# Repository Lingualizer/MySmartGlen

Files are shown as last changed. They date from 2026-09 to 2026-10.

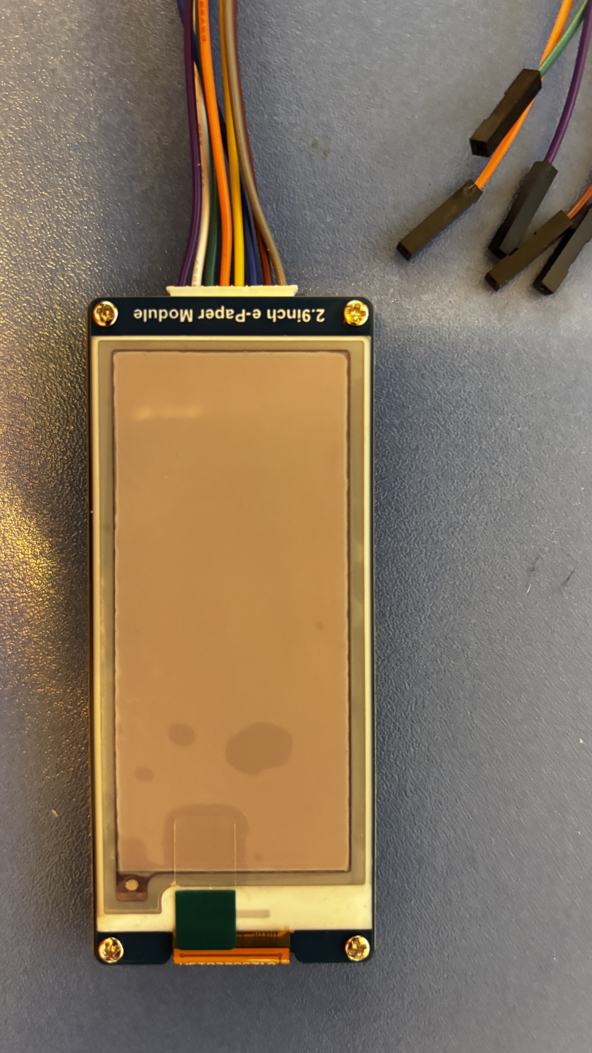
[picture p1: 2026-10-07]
Components/2.9 e-Paper Waveshare/2.9 Waveshare ePaper FRONT.jpeg

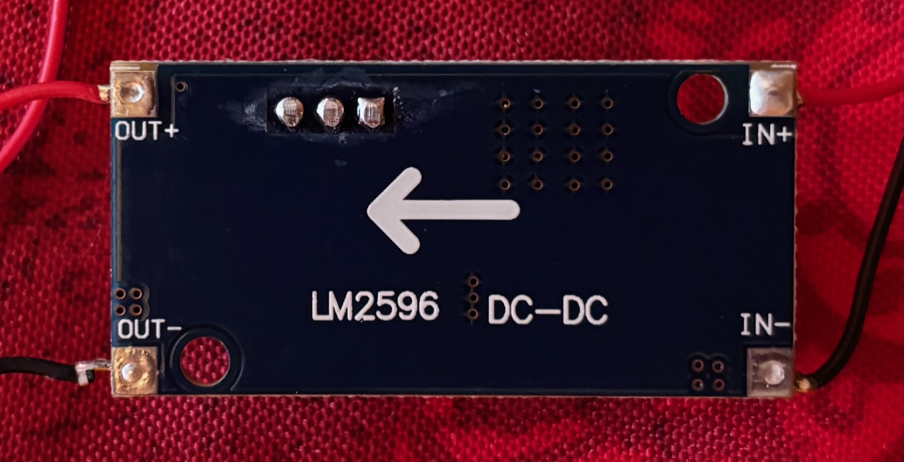
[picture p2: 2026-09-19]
Components/LM2596/LM2596 DC-DC bottom.jpeg

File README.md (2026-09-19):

## Hardware-Übersicht

### Controller & Module
| 🟡 Testaufbau | 🟢 Verbaut | 🔴 Geplant |
| Node ID | Board / Chip | Standby / Load | Bus / IP | Einbauort | Status | Link |
| :--- | :--- | :--- | :--- | :--- | :--- | :--- |
| `Display` | ESP32-S3 (4" Touch) | ~150mA | 192.168.1.220 | Sitzgruppe | 🟡 |  |
| `KS Abluft` | ESP32 NodeMCU | ~80mA | 192.168.1.228 | Hinter Kühlschrank-Gitter | 🟡 | https://www.amazon.de/dp/B0FRF24HL9 |
| `Frischschwasser` | ESP32 NodeMCU | ~50mA | 192.168.1.197 | Sitzbank / Tankbereich | 🟡 | https://www.amazon.de/dp/B0FRF24HL9 |

### Verbaute Sensoren & Aktoren
| Komponente | Typ / Modell | Angeschlossen an | Signal / Protokoll | Pins (ESP32) |
| :--- | :--- | :--- | :--- | :--- |
| Abluft-Sensor | SHT31 | `esp-fridge` | OneWire | GPIO 4 |
| Innen-Temp. | ? | `esp-fridge` | OneWire | GPIO 4 (Bus) |
| Gefrierfach-Temp. | ? | `esp-fridge` | OneWire | GPIO 4 (Bus) |
| Abluft-Lüfter | 12V Noctua PWM | `esp-fridge` | PWM / MOSFET | GPIO 16 (PWM), GPIO 17 (Tacho) |
| Urintank Level | XKC-Y25-V (Kapazitiv) | `esp-tanks` | Digital (High/Low) | GPIO 18 |
| Frischwasser | 10-Stufen-Sonde | `esp-tanks` | Analog / ADC | GPIO 34 |

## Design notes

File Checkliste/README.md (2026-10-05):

# Abfahrts-Checkliste

Eigenstaendiges PlatformIO-Projekt fuer ein ESP32-DevKit und ein
Waveshare 2.9-inch e-Paper V2 (296 x 128, schwarz/weiss, SSD1680). Die
Firmware nimmt diese Panel-Revision an; bei einer aelteren 2.9-inch-Version
muss der GxEPD2-Paneltyp angepasst werden.

## Bedienung

Mit `Hoch` und `Runter` wird der Cursor durch die Liste bewegt. Die
Navigation laeuft am Listenende weiter zum Anfang und umgekehrt. Ein kurzer
Druck auf `Auswahl` setzt oder entfernt das Haekchen des markierten Punkts.
Wird `Auswahl` 1,2 Sekunden gehalten, werden alle Haekchen geloescht und der
Cursor springt zum ersten Eintrag. Sind alle Punkte bestaetigt, erscheint
gross **OK**. Der Zustand wird nicht dauerhaft gespeichert und startet nach
einem Neustart wieder offen.

## Liste anpassen

Pruefpunkte werden in `src/main.cpp` im Array `checklist` gepflegt:

```cpp
{"Gasflasche geschlossen", false},
```

Weitere Eintraege vor der schliessenden Klammer des Arrays ergaenzen. Die
Anzeige scrollt automatisch mit dem Cursor und zeigt jeweils bis zu acht
Punkte.

## Verdrahtung

Verdrahtungsschaltplan

| Signal | ESP32 GPIO |
| --- | ---: |
| e-Paper CLK (ESP32 SCK) | 18 |
| e-Paper MOSI / DIN | 23 |
| e-Paper CS | 5 |
| e-Paper DC | 17 |
| e-Paper RST | 16 |
| e-Paper BUSY | 4 |
| Hoch | 33 |
| Runter | 32 |
| Auswahl / lang halten fuer Reset | 25 |

Alle Taster werden zwischen ihrem GPIO und GND angeschlossen. Die Firmware
aktiviert `INPUT_PULLUP`; ein Tastendruck ist daher LOW. Das Display wird
mit 3.3 V betrieben. Beim e-Paper-Modul die beschrifteten Anschluesse
verwenden und nicht mit 5 V versorgen.

`CLK` am Waveshare-Modul ist derselbe SPI-Takt wie `SCK` am ESP32: GPIO 18
geht an `CLK`, GPIO 23 (MOSI) geht an `DIN`. Diese beiden Leitungen nicht
vertauschen.

## Bauen und Flashen

Im Ordner `Checkliste`:

```sh
pio run
pio run --target upload
pio device monitor
```

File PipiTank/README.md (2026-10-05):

# PipiTank-Sensortest

Serieller Funktionstest fuer die zwei XKC-Y25-NPN-Sensoren gemaess
`Urintank-Schaltplan.pdf`.

## Belegung

| Signal | Anschluss |
| --- | --- |
| Sensor 1 OUT, gelb | ESP32 GPIO 18 |
| Sensor 2 OUT, gelb | ESP32 GPIO 19 |
| Beide Sensoren GND, blau | Gemeinsame Masse mit ESP32 |
| Beide Sensoren VCC, braun | 12-V-Versorgung gemaess Schaltplan |
| Mode, schwarz | Nicht angeschlossen gemaess Schaltplan |

Die gelben NPN-Open-Collector-Ausgaenge werden mit `INPUT_PULLUP` gelesen.
LOW bedeutet Sensor erkannt, HIGH bedeutet nicht erkannt. Die 12-V-Versorgung
nicht mit einem ESP32-GPIO verbinden; nur die OUT-Leitung geht an den GPIO.

## Testen

Im Ordner `PipiTank` ausfuehren:

```sh
pio run
pio run --target upload
pio device monitor
```

Der serielle Monitor laeuft mit 115200 Baud und gibt beide Pegel zweimal pro
Sekunde samt Rohwert aus.

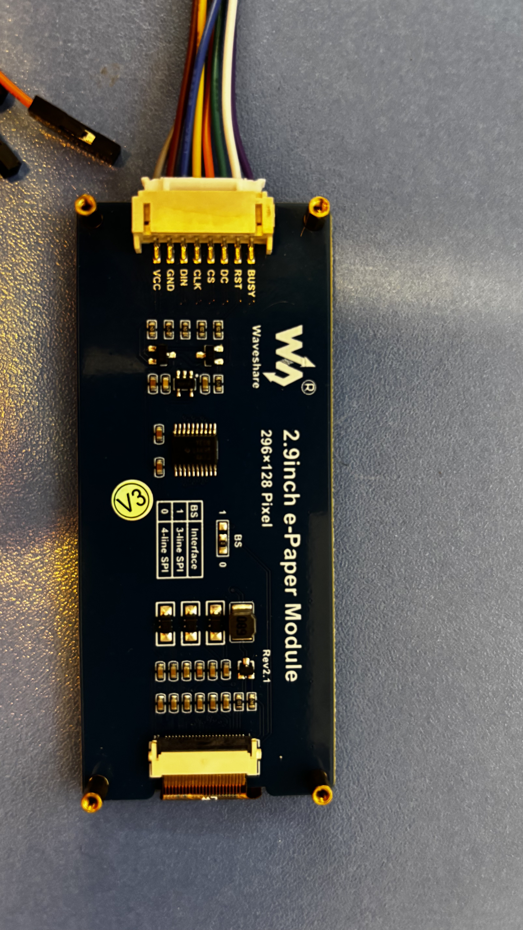
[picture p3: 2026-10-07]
Checkliste/2.9 Waveshare ePaper back.jpeg

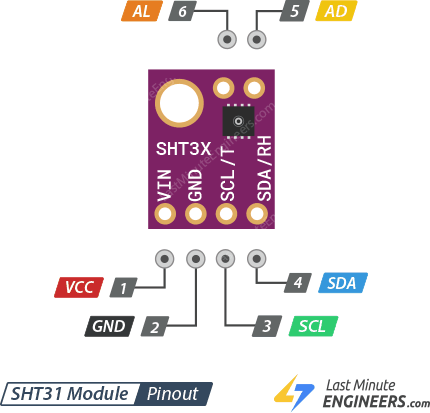
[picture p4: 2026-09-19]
Components/SHT31/SHT31-Module-Pinout.png

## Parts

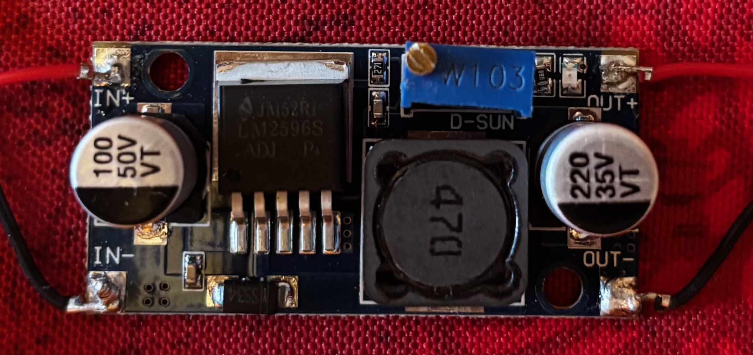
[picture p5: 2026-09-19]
Components/LM2596/LM2596 DC-DC top.jpeg

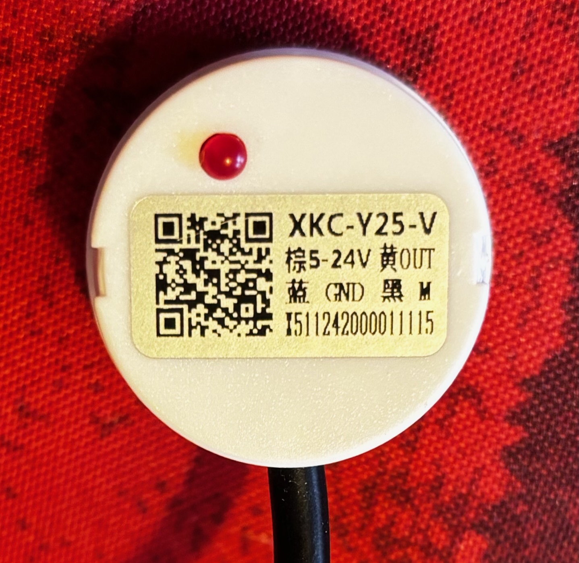
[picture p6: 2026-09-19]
Components/XKC-Y25-V/XKC-Y25-V.jpeg

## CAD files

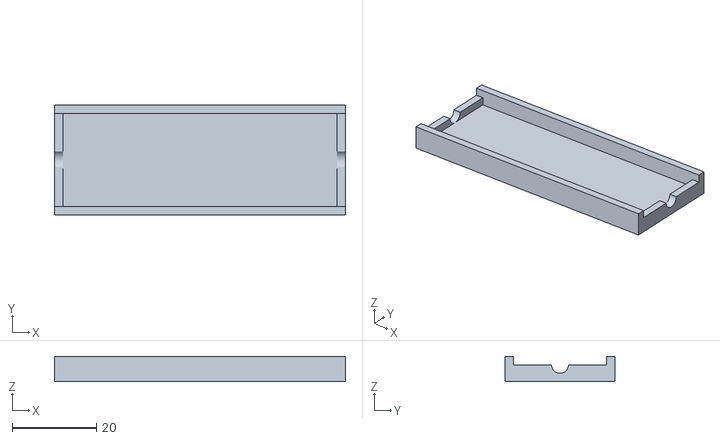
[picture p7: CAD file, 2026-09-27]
Components/LM2596/LM2596 Case.stl
69.0 x 26.0 x 6.00

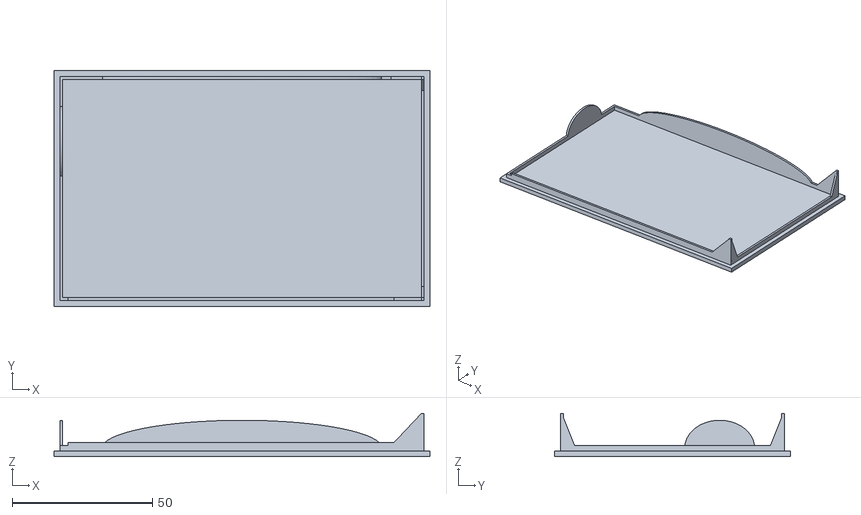
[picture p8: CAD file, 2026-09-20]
Display/Case/ESP32-DisplayCover-2.stl
134.0 x 84.0 x 15.5

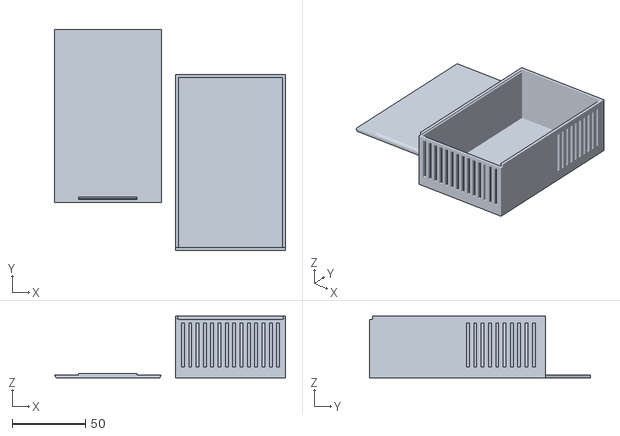
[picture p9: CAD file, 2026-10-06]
PipiTank/PipiLevel Gehäuse-2.stl
157.6 x 150.5 x 42.0

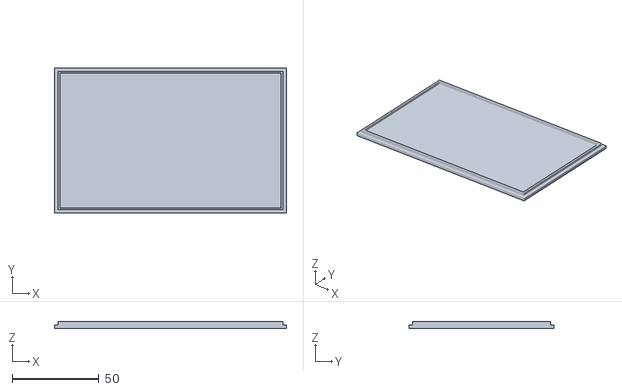
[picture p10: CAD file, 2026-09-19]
Display/Case/ESP32-DisplayCover.stl
134.0 x 84.0 x 4.00

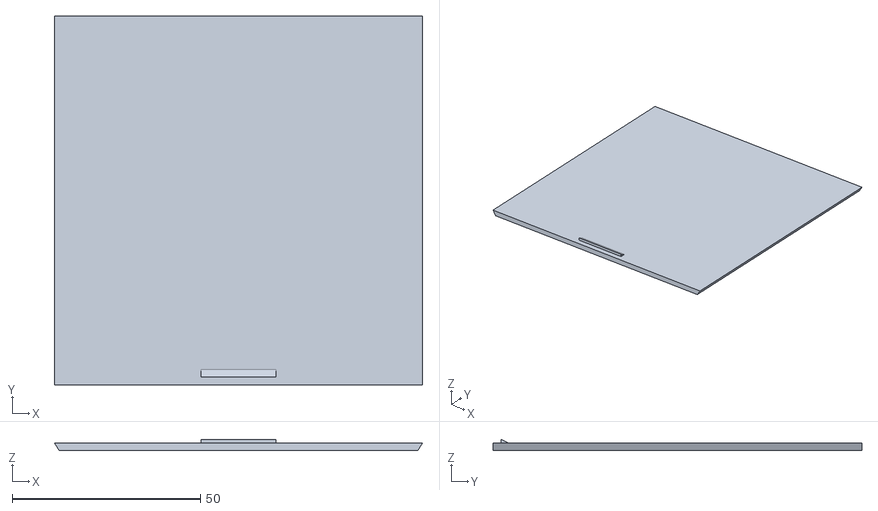
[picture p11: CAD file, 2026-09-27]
Frischwasser/Case/ESP32 Level Case and Lid.stl
97.8 x 98.0 x 3.00

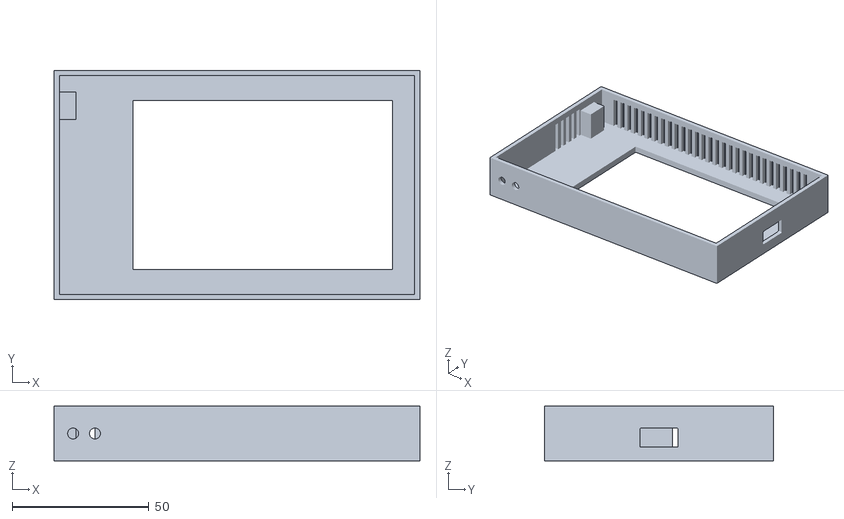
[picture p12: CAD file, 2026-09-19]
Display/Case/ESP32-DisplayCase.stl
134.0 x 84.0 x 20.0

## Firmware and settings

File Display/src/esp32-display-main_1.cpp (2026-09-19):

/*
  ============================================================
  MOTORHOME HOMESCREEN v3 -- Echte WLAN-Konfiguration
  ============================================================

  NEU gegenueber v2:
  - Settings: "WLAN" oeffnet echte Netzwerksuche
  - Liste gefundener Netzwerke antippen -> Passwort-Eingabe
    mit Bildschirmtastatur -> Verbinden
  - Erfolgreiche Zugangsdaten werden im Flash gespeichert
    (Preferences/NVS) und beim naechsten Start automatisch
    wiederverwendet (Auto-Reconnect)
  - Status-Icon oben links zeigt Verbindungsstatus:
    grau=getrennt, gelb=verbindet, gruen=verbunden

  NEU (25.08.2026): Frischwasser-Kachel zeigt jetzt den echten
  Fuellstand vom Frischwasser-Node (3 Schwellwert-Sensoren per
  HTTP/WLAN), statt eines statischen Platzhalters. Siehe Abschnitt
  "Frischwasser-Node" weiter unten.

  ANNAHME: Datum/Uhrzeit bleibt vorerst die manuelle Software-
  Uhr aus v2 -- echte NTP-Synchronisation ueber das jetzt
  vorhandene WLAN waere der naechste sinnvolle Ausbauschritt,
  aber bewusst noch nicht Teil dieser Aenderung.
  ============================================================
*/

#include <lvgl.h>
#include <TFT_eSPI.h>
#include <WiFi.h>
#include <HTTPClient.h>
#include <ArduinoJson.h>
#include <Preferences.h>
#include <time.h>
#include <Wire.h>

// Eigene Schriftarten mit deutschen Umlauten (Ä/Ö/Ü/ä/ö/ü/ß),
// erstellt via lv_font_conv, ersetzen die eingebauten
// lv_font_montserrat_14/20 (die nur ASCII enthalten).
LV_FONT_DECLARE(lv_font_montserrat_14_de);
LV_FONT_DECLARE(lv_font_montserrat_20_de);

TFT_eSPI tft = TFT_eSPI();
Preferences prefs;

static lv_disp_draw_buf_t draw_buf;
static lv_color_t buf1[480 * 40];

// Kalibrierung als lineare Formel (Steigung + Achsenabschnitt)
float slopeY = -479.0f / (3850 - 200);
float interceptY = 479.0f - slopeY * 200;
float slopeX = -319.0f / (3750 - (-50));
float interceptX = 319.0f - slopeX * (-50);
const uint8_t TOUCH_Z_THRESHOLD = 25; // erhoeht von 15 -- Rauschen erreichte bis zu z=14

// Display-Ausrichtung: false = normal (USB rechts), true = um 180 Grad
// gedreht (USB links). Wird dauerhaft gespeichert (Preferences/NVS).
bool displayFlipped = false;

// DIAGNOSE-MODUS: Zum Herausfinden, welcher TFT_eSPI-Rotationswert
// bei diesem Treiber tatsaechlich einer sauberen 180-Grad-Drehung
// entspricht (0-3 durchprobieren). Sobald bekannt, wird das oben
// auf einen festen Wert reduziert.
int rotationTestIndex = 1;

const int BACKLIGHT_PIN = 27;

lv_obj_t *scr_home;
lv_obj_t *scr_vedirect_detail;
lv_obj_t *scr_settings;
lv_obj_t *scr_calibration;
lv_obj_t *scr_wifi_list;
lv_obj_t *scr_wifi_password;
lv_obj_t *scr_kuehlschrank;

// VE.Direct UI-Elemente (vorab deklariert, da build_home_screen()
// schon vor der eigentlichen VE.Direct-Sektion im Code steht)
lv_obj_t *tile_solar_value = NULL;
lv_obj_t *ve_solarleistung_val = NULL;
lv_obj_t *ve_batteriespannung_val = NULL;
lv_obj_t *ve_ladestrom_val = NULL;
lv_obj_t *ve_tagesertrag_val = NULL;
lv_obj_t *ve_ladezustand_val = NULL;

// SHT31 (RT/H) -- ebenfalls vorab deklariert
lv_obj_t *tile_rth_value = NULL;

// KS Abluft -- Temperatur/Feuchte vom Lüfter-Node (ebenfalls vorab
// deklariert, siehe Abschnitt "Lüfter-Node" weiter unten)
lv_obj_t *tile_ksabluft_value = NULL;
lv_obj_t *tile_ksabluft_progress = NULL; // schmaler Balken: Zeit bis zur naechsten Abfrage

// Frischwasser -- Fuellstand vom Frischwasser-Node (ebenfalls vorab
// deklariert, siehe Abschnitt "Frischwasser-Node" weiter unten)
lv_obj_t *tile_frischwasser_value = NULL;
lv_obj_t *tile_frischwasser_fill = NULL; // dynamisch aktualisierter Fuellstands-Hintergrund

// Batterie -- Fuellstand (SOC) vom Victron Shunt (VE.Direct, UART1,
// GPIO35 -- ebenfalls vorab deklariert, siehe Abschnitt "Victron Shunt"
// weiter unten)
lv_obj_t *tile_batterie_value = NULL;
lv_obj_t *tile_batterie_fill = NULL;

// ---- Statusleiste / WLAN-Symbol (global, damit von loop() aus
//      aktualisierbar) ----
lv_obj_t *home_wifi_icon = NULL;
lv_obj_t *settings_wifi_status = NULL;

// ---- WLAN-Verbindungsstatus ----
bool wifiConnecting = false;
unsigned long wifiConnectStart = 0;
const unsigned long WIFI_CONNECT_TIMEOUT = 15000;
String pendingSSID;

// ---- Software-Uhr ----
volatile int clockHour = 12;
volatile int clockMinute = 0;
unsigned long lastMinuteMillis = 0;
lv_obj_t *time_label_settings = NULL;
lv_obj_t *time_source_label = NULL;
bool ntpSyncRequested = false;
bool ntpSynced = false;
unsigned long lastNtpCheckMillis = 0;

// ---- Kalibrierungs-Ablauf ----
bool calibrating = false;
int calibStep = 0;
struct CalPoint { int x, y; const char* name; };
CalPoint calTargets[4] = {
  {40,  35,  "oben-links"},
  {440, 35,  "oben-rechts"},
  {40,  270, "unten-links"},
  {440, 270, "unten-rechts"}
};
int calRawX[4], calRawY[4];
lv_obj_t *calib_label = NULL;
lv_obj_t *calib_crosshair_h = NULL;
lv_obj_t *calib_crosshair_v = NULL;

// ---- WLAN-UI-Elemente ----
lv_obj_t *wifi_list_obj = NULL;
lv_obj_t *wifi_ip_mac_label = NULL;
lv_obj_t *wifi_password_ssid_label = NULL;
lv_obj_t *wifi_password_status_label = NULL;
lv_obj_t *wifi_password_textarea = NULL;
lv_obj_t *wifi_keyboard = NULL;

// ---- Kuehlschrank-Knoten UI-Elemente ----
Preferences fridgePrefs;
lv_obj_t *fridge_ip_textarea = NULL;
lv_obj_t *fridge_status_label = NULL;
lv_obj_t *fridge_on_textarea = NULL;
lv_obj_t *fridge_off_textarea = NULL;
lv_obj_t *fridge_result_label = NULL;
lv_obj_t *fridge_keyboard = NULL;

// ---- Diagnose/Checks-Bildschirm (manuelle Sofort-Abfrage bekannter
//      Knoten, ohne IP am Handy abtippen zu muessen) ----
lv_obj_t *scr_checks;
bool checksScreenBuilt = false; // Diagnose-Seite wird erst bei Bedarf angelegt, siehe go_checks_cb()
lv_obj_t *check_frischwasser_result = NULL;
lv_obj_t *check_ksabluft_result = NULL;
lv_obj_t *check_kuehlschrank_result = NULL;

// --- Display-Flush ---
void my_disp_flush(lv_disp_drv_t *disp, const lv_area_t *area, lv_color_t *color_p) {
  uint32_t w = (area->x2 - area->x1 + 1);
  uint32_t h = (area->y2 - area->y1 + 1);

  tft.startWrite();

  if (displayFlipped) {
    // Software-180-Grad-Drehung: Zielbereich spiegeln (statt der
    // Hardware-Rotation zu vertrauen, die bei diesem Treiber fuer
    // Hochformat-Modi nicht sauber funktioniert) UND die Pixel-
    // Reihenfolge komplett umkehren, da eine 180-Grad-Drehung
    // exakt einer umgekehrten Auslese des Puffers entspricht.
    int32_t mirroredX1 = 479 - area->x2;
    int32_t mirroredY1 = 319 - area->y2;

    uint32_t total = w * h;
    uint16_t *src = (uint16_t *)&color_p->full;
    uint16_t *reversed = (uint16_t *)malloc(total * sizeof(uint16_t));
    if (reversed) {
      for (uint32_t i = 0; i < total; i++) {
        reversed[i] = src[total - 1 - i];
      }
      tft.setAddrWindow(mirroredX1, mirroredY1, w, h);
      tft.pushColors(reversed, total, true);
      free(reversed);
    } else {
      // Speicher knapp -- Fallback ohne Drehung, besser als Absturz
      tft.setAddrWindow(area->x1, area->y1, w, h);
      tft.pushColors(src, total, true);
    }
  } else {
    tft.setAddrWindow(area->x1, area->y1, w, h);
    tft.pushColors((uint16_t *)&color_p->full, w * h, true);
  }

  tft.endWrite();
  lv_disp_flush_ready(disp);
}

bool readTouchSmoothed(int &px, int &py) {
  const int SAMPLES = 6; // erhoeht von 4 -- mehr Samples = Rauschen muesste noch oefter zufaellig treffen
  long sumRawX = 0, sumRawY = 0;
  int validCount = 0;

  for (int i = 0; i < SAMPLES; i++) {
    uint16_t rawX, rawY;
    if (tft.getTouchRaw(&rawX, &rawY)) {
      uint8_t z = tft.getTouchRawZ();
      if (z >= TOUCH_Z_THRESHOLD) {
        sumRawX += rawX;
        sumRawY += rawY;
        validCount++;
      }
    }
    delayMicroseconds(500);
  }

  if (validCount < SAMPLES) return false;

  int rawX = sumRawX / validCount;
  int rawY = sumRawY / validCount;

  px = (int)(slopeY * rawY + interceptY);
  py = (int)(slopeX * rawX + interceptX);

  // Bei gedrehtem Display (180 Grad) muessen auch die Touch-
  // Koordinaten gespiegelt werden, da der Touch-Sensor physisch
  // fest sitzt und sich nicht mitdreht.
  if (displayFlipped) {
    px = 479 - px;
    py = 319 - py;
  }

  px = constrain(px, 0, 479);
  py = constrain(py, 0, 319);
  return true;
}

void my_touchpad_read(lv_indev_drv_t *indev_drv, lv_indev_data_t *data) {
  if (calibrating) {
    data->state = LV_INDEV_STATE_RELEASED;
    return;
  }
  int px, py;
  if (readTouchSmoothed(px, py)) {
    data->point.x = px;
    data->point.y = py;
    data->state = LV_INDEV_STATE_PRESSED;
  } else {
    data->state = LV_INDEV_STATE_RELEASED;
  }
}

// ============================================================
// Kachel-Hilfsfunktion (Startseite)
// ============================================================
// Kachel mit optionalem Fuellstands-Hintergrund (fill_percent 0-100,
// oder -1 fuer keine Fuellanzeige -- normale Kachel wie bisher).
// Der Fuellbalken wird halbtransparent hinter Titel/Wert gezeichnet,
// damit der Text weiterhin gut lesbar bleibt.
lv_obj_t *create_tile(lv_obj_t *parent, int col, int row, const char *title,
                       const char *value, lv_color_t accent_color, int fill_percent = -1) {
  const int TILE_W = 112;
  const int TILE_H = 130;
  const int GAP = 6;
  const int START_X = 6;
  const int START_Y = 4;

  lv_obj_t *tile = lv_btn_create(parent);
  lv_obj_set_size(tile, TILE_W, TILE_H);
  lv_obj_set_pos(tile, START_X + col * (TILE_W + GAP), START_Y + row * (TILE_H + GAP));
  lv_obj_set_style_bg_color(tile, lv_color_hex(0x1E1E1E), 0);
  lv_obj_set_style_border_color(tile, accent_color, 0);
  lv_obj_set_style_border_width(tile, 2, 0);
  lv_obj_set_style_radius(tile, 8, 0);
  lv_obj_set_style_clip_corner(tile, true, 0); // Fuellung an abgerundeten Ecken abschneiden
  lv_obj_clear_flag(tile, LV_OBJ_FLAG_SCROLLABLE);

  if (fill_percent >= 0) {
    int fh = (int)((TILE_H - 4) * (constrain(fill_percent, 0, 100) / 100.0f));
    lv_obj_t *fill = lv_obj_create(tile);
    lv_obj_remove_style_all(fill);
    lv_obj_set_size(fill, TILE_W - 4, fh);
    lv_obj_set_pos(fill, 2, (TILE_H - 2) - fh);
    lv_obj_set_style_bg_color(fill, accent_color, 0);
    lv_obj_set_style_bg_opa(fill, LV_OPA_40, 0);
    lv_obj_set_style_radius(fill, 6, 0);
    lv_obj_clear_flag(fill, LV_OBJ_FLAG_SCROLLABLE);
    lv_obj_clear_flag(fill, LV_OBJ_FLAG_CLICKABLE);
  }

  lv_obj_t *title_label = lv_label_create(tile);
  lv_label_set_text(title_label, title);
  lv_label_set_long_mode(title_label, LV_LABEL_LONG_WRAP);
  lv_obj_set_width(title_label, TILE_W - 12);
  lv_obj_set_style_text_align(title_label, LV_TEXT_ALIGN_CENTER, 0);
  lv_obj_set_style_text_font(title_label, &lv_font_montserrat_14_de, 0);
  lv_obj_align(title_label, LV_ALIGN_TOP_MID, 0, 6);

  lv_obj_t *value_label = lv_label_create(tile);
  lv_label_set_text(value_label, value);
  lv_obj_set_style_text_font(value_label, &lv_font_montserrat_20_de, 0);
  lv_obj_set_style_text_color(value_label, accent_color, 0);
  // Sicherheitsnetz gegen Ueberlauf bei groesserer Schrift (siehe Notizen):
  // Breite begrenzen + bei Platzmangel mit "..." abschneiden statt in die
  // Nachbarkachel zu ragen. Bei der aktuellen 20px-Schrift greift das nicht.
  //
  // WICHTIG: Hoehe wird explizit fuer bis zu 2 Zeilen reserviert (per
  // Font-Metrik berechnet, nicht geschaetzt). Ohne diese Zeile wuerde
  // LV_LABEL_LONG_DOT die Hoehe anhand des *Platzhaltertexts* an dieser
  // Stelle einfrieren -- bei einzeiligen Platzhaltern wie "--" (RT/H,
  // KS Abluft) verschwand dadurch die spaeter per Code gesetzte zweite
  // Zeile (Feuchte) kommentarlos. Bug gefunden am 23.08.2026.
  lv_obj_set_width(value_label, TILE_W - 8);
  lv_obj_set_height(value_label, lv_font_get_line_height(&lv_font_montserrat_20_de) * 2 + 2);
  lv_label_set_long_mode(value_label, LV_LABEL_LONG_DOT);
  lv_obj_set_style_text_align(value_label, LV_TEXT_ALIGN_CENTER, 0);
  lv_obj_align(value_label, LV_ALIGN_BOTTOM_MID, 0, -8);

  return tile;
}

// ============================================================
// Bildschirmwechsel-Callbacks
// ============================================================
static void go_home_cb(lv_event_t *e) { lv_scr_load(scr_home); }
static void go_settings_cb(lv_event_t *e) {
  lv_scr_load(scr_settings);
}
static void vedirect_tile_event_cb(lv_event_t *e) { lv_scr_load(scr_vedirect_detail); }
// Vorab deklariert -- die eigentliche Definition steht weiter unten
// beim Diagnose/Checks-Bildschirm, wird aber schon hier in add_status_bar()
// als Button-Callback gebraucht.
static void go_checks_cb(lv_event_t *e);

// ============================================================
// Statusleiste
// ============================================================
void add_status_bar(lv_obj_t *screen) {
  lv_obj_t *bar = lv_obj_create(screen);
  lv_obj_set_size(bar, 480, 36);
  lv_obj_set_pos(bar, 0, 0);
  lv_obj_set_style_bg_color(bar, lv_color_hex(0x000000), 0);
  lv_obj_set_style_border_width(bar, 0, 0);
  lv_obj_set_style_radius(bar, 0, 0);
  lv_obj_clear_flag(bar, LV_OBJ_FLAG_SCROLLABLE);

  lv_obj_t *wifi_icon = lv_label_create(bar);
  lv_label_set_text(wifi_icon, LV_SYMBOL_WIFI);
  lv_obj_set_style_text_color(wifi_icon, lv_color_hex(0x666666), 0);
  lv_obj_align(wifi_icon, LV_ALIGN_LEFT_MID, 8, 0);
  home_wifi_icon = wifi_icon; // global merken fuer spaetere Farb-Updates

  // Deutlich vergroessert (war 34x22) -- kleine Ecken-Buttons sind
  // beim resistiven Touch am ungenauesten zu treffen.
  lv_obj_t *settings_btn = lv_btn_create(bar);
  lv_obj_set_size(settings_btn, 64, 34);
  lv_obj_align(settings_btn, LV_ALIGN_RIGHT_MID, -4, 0);
  lv_obj_set_style_bg_color(settings_btn, lv_color_hex(0x1E1E1E), 0);
  lv_obj_set_style_border_width(settings_btn, 0, 0);
  lv_obj_add_event_cb(settings_btn, go_settings_cb, LV_EVENT_CLICKED, NULL);

  lv_obj_t *gear_label = lv_label_create(settings_btn);
  lv_label_set_text(gear_label, LV_SYMBOL_SETTINGS);
  lv_obj_center(gear_label);

  // Diagnose/Checks-Button links neben dem Zahnrad (ANNAHME: LV_SYMBOL_LIST
  // als Icon fuer "Checks" gewaehlt, da LVGL kein spezifisches
  // Diagnose-Symbol mitbringt -- bei Bedarf leicht gegen ein anderes
  // eingebautes Symbol tauschbar).
  lv_obj_t *checks_btn = lv_btn_create(bar);
  lv_obj_set_size(checks_btn, 64, 34);
  lv_obj_align(checks_btn, LV_ALIGN_RIGHT_MID, -74, 0);
  lv_obj_set_style_bg_color(checks_btn, lv_color_hex(0x1E1E1E), 0);
  lv_obj_set_style_border_width(checks_btn, 0, 0);
  lv_obj_add_event_cb(checks_btn, go_checks_cb, LV_EVENT_CLICKED, NULL);

  lv_obj_t *checks_label = lv_label_create(checks_btn);
  lv_label_set_text(checks_label, LV_SYMBOL_LIST);
  lv_obj_center(checks_label);
}

// Aktualisiert Farbe des WLAN-Symbols entsprechend Verbindungsstatus.
void update_wifi_icon() {
  if (!home_wifi_icon) return;
  if (WiFi.status() == WL_CONNECTED) {
    lv_obj_set_style_text_color(home_wifi_icon, lv_color_hex(0x4CAF50), 0); // gruen
  } else if (wifiConnecting) {
    lv_obj_set_style_text_color(home_wifi_icon, lv_color_hex(0xFFC107), 0); // gelb
  } else {
    lv_obj_set_style_text_color(home_wifi_icon, lv_color_hex(0x666666), 0); // grau
  }
}

void update_settings_wifi_status() {
  if (!settings_wifi_status) return;
  if (WiFi.status() == WL_CONNECTED) {
    lv_label_set_text_fmt(settings_wifi_status, "Verbunden: %s", WiFi.SSID().c_str());
    lv_obj_set_style_text_color(settings_wifi_status, lv_color_hex(0x4CAF50), 0);
  } else if (wifiConnecting) {
    lv_label_set_text(settings_wifi_status, "Verbinde...");
    lv_obj_set_style_text_color(settings_wifi_status, lv_color_hex(0xFFC107), 0);
  } else {
    lv_label_set_text(settings_wifi_status, "Nicht verbunden");
    lv_obj_set_style_text_color(settings_wifi_status, lv_color_hex(0x888888), 0);
  }
}
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
void loop() {
  lv_timer_handler();

  handleVeDirectSerial();
  handleShuntSerial();
  handleRthSensor();
  handleKsAbluftSensor();
  updateKsAbluftProgressBar();
  handleFrischwasserSensor();

  if (calibrating) {
    calib_process();
  }

  // WLAN-Verbindungsversuch ueberwachen
  if (wifiConnecting) {
    if (WiFi.status() == WL_CONNECTED) {
      wifiConnecting = false;
      Serial.printf("WLAN verbunden: %s\n", WiFi.SSID().c_str());
      Serial.printf("IP-Adresse: %s\n", WiFi.localIP().toString().c_str());
      Serial.printf("MAC-Adresse: %s (fuer DHCP-Reservierung im Router)\n", WiFi.macAddress().c_str());

      // Zugangsdaten speichern (nur wenn ueber die Passwort-Eingabe
      // ausgeloest -- pendingSSID ist dann gesetzt)
      if (pendingSSID.length() > 0 && pendingSSID == WiFi.SSID()) {
        prefs.begin("wifi", false);
        prefs.putString("ssid", WiFi.SSID());
        prefs.putString("pass", lv_textarea_get_text(wifi_password_textarea));
        prefs.end();
        pendingSSID = "";
      }

      update_wifi_icon();
      update_settings_wifi_status();
      update_wifi_ip_mac_label();
      if (wifi_password_status_label) {
        lv_label_set_text(wifi_password_status_label, "Verbunden!");
        lv_obj_set_style_text_color(wifi_password_status_label, lv_color_hex(0x4CAF50), 0);
      }

      // Sobald WLAN steht: NTP-Zeitsynchronisation anstossen
      startNtpSync();
    } else if (millis() - wifiConnectStart > WIFI_CONNECT_TIMEOUT) {
      wifiConnecting = false;
      Serial.println("WLAN-Verbindung fehlgeschlagen (Timeout).");
      update_wifi_icon();
      update_settings_wifi_status();
      if (wifi_password_status_label) {
        lv_label_set_text(wifi_password_status_label, "Fehlgeschlagen");
        lv_obj_set_style_text_color(wifi_password_status_label, lv_color_hex(0xF44336), 0);
      }
    }
  }

  // Software-Uhr: nur hochzaehlen, wenn (noch) keine NTP-Synchronisation
  // erfolgt ist. Sobald NTP synchronisiert hat, kommt die Zeit direkt
  // aus checkNtpResult() -- das manuelle Hochzaehlen wuerde sonst mit
  // der echten Systemzeit driften.
  if (!ntpSynced && millis() - lastMinuteMillis >= 60000) {
    lastMinuteMillis += 60000;
    clockMinute++;
    if (clockMinute >= 60) { clockMinute = 0; clockHour = (clockHour + 1) % 24; }
    update_time_label();
  }

  // NTP-Ergebnis regelmaessig pruefen (auch nach erfolgreicher erster
  // Synchronisation, damit sich die angezeigte Minute weiter aktualisiert)
  if (millis() - lastNtpCheckMillis >= 20000) {
    lastNtpCheckMillis = millis();
    checkNtpResult();
  }
  static unsigned long lastResyncMillis = 0;
  if (ntpSynced && millis() - lastResyncMillis >= 6UL * 60 * 60 * 1000) {
    lastResyncMillis = millis();
    startNtpSync();
  }

  delay(5);
}

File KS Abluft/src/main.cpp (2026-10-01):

/*
 * Lüfter-Node: Abluft-Temperaturüberwachung + Lüftersteuerung
 * -------------------------------------------------------------
 * - 1x SHT31 (I2C) am Abluft/Lüftungsgitter (ersetzt DS18B20)
 * - Lüfter über BC547 NPN-Transistor an GPIO5 (active-HIGH)
 * - Hysterese-Schwellwerte in NVS Preferences gespeichert,
 *   per HTTP /config änderbar
 * - WLAN: feste Zugangsdaten (Variante A)
 * - HTTP-API: GET /status liefert aktuellen Zustand als JSON
 *
 * Sensorwechsel DS18B20 -> SHT31 (I2C statt 1-Wire):
 * - Benötigt Library "Adafruit SHT31 Library" (+ Abhängigkeit
 *   "Adafruit BusIO"), siehe lib_deps in platformio.ini.
 * - GPIO4 (ehem. 1-Wire-Bus) ist aktuell frei; laut Original-Kommentar
 *   ggf. später für weitere DS18B20 (Kühlschrank/Gefrierfach) reserviert.
 * - SHT31 liefert zusätzlich Luftfeuchtigkeit; diese wird hier
 *   ergänzend im JSON mit ausgegeben (Erweiterung ggü. Original,
 *   nicht Teil der ursprünglichen Anforderung).
 */

#if __has_include(<Arduino.h>)
#include <Arduino.h>
#elif __has_include(<WProgram.h>)
#include <WProgram.h>
#else
#error "Arduino core headers are unavailable; configure this project with an Arduino-compatible PlatformIO environment."
#endif
#include <WiFi.h>
#include <WebServer.h>
#include <Preferences.h>
#include <Wire.h>
#include "Adafruit_SHT31.h"
#include <ArduinoJson.h>

// ---------- WLAN Zugangsdaten (Variante A: fest im Code) ----------
const char* WIFI_SSID     = "DIGIFIBRA-LiPe";
const char* WIFI_PASSWORD = "Wl@nL14n3P3t3r";

// ---------- Pin-Belegung ----------
#define I2C_SDA        21   // SHT31 Datenleitung (I2C)
#define I2C_SCL        22   // SHT31 Taktleitung (I2C)
#define FAN_PIN        5    // BC547 Basis über 1kOhm, active-HIGH

#define SHT31_I2C_ADDR 0x44 // Standardadresse; 0x45 falls ADR-Pin auf HIGH

// ---------- Hysterese Default-Werte (nur falls NVS leer) ----------
// ANNAHME, nicht validiert: Startwerte, bis reale Messwerte
// (Oberflächentemperatur unter Sonneneinstrahlung) vorliegen.
#define DEFAULT_TEMP_ON   30.0f   // Lüfter EIN ab dieser Temperatur
#define DEFAULT_TEMP_OFF  25.0f   // Lüfter AUS unterhalb dieser Temperatur

// ---------- Globale Objekte ----------
Adafruit_SHT31 sht31 = Adafruit_SHT31();
WebServer server(80);
Preferences prefs;

float tempOn  = DEFAULT_TEMP_ON;
float tempOff = DEFAULT_TEMP_OFF;
float currentTemp = NAN;
float minTemp = NAN;
float maxTemp = NAN;
float currentHumidity = NAN;
bool fanState = false;
bool sensorOk = false; // wird in setup() gesetzt, falls SHT31 beim Start gefunden wurde

unsigned long lastMeasurement = 0;
const unsigned long MEASURE_INTERVAL_MS = 5000; // alle 5s messen

// ---------- Hysterese-Werte aus NVS laden ----------
void loadThresholds() {
  prefs.begin("luefter", true); // read-only
  tempOn  = prefs.getFloat("temp_on",  DEFAULT_TEMP_ON);
  tempOff = prefs.getFloat("temp_off", DEFAULT_TEMP_OFF);
  prefs.end();
}

// ---------- Hysterese-Werte in NVS speichern ----------
void saveThresholds(float onVal, float offVal) {
  prefs.begin("luefter", false); // read-write
  prefs.putFloat("temp_on", onVal);
  prefs.putFloat("temp_off", offVal);
  prefs.end();
}

// ---------- Temperatur/Feuchte messen + Lüfterlogik ----------
void updateTemperatureAndFan() {
  float t;
  float h;
  if (!sht31.readBoth(&t, &h)) {
    // Sensor nicht erreichbar - Lüfter aus Sicherheitsgründen NICHT
    // automatisch abschalten, aber Fehler klar signalisieren.
    Serial.println("Fehler: SHT31 nicht erreichbar!");
    return;
  }

  currentTemp = t;
  currentHumidity = h;
  if (isnan(minTemp) || currentTemp < minTemp) {
    minTemp = currentTemp;
  }
  if (isnan(maxTemp) || currentTemp > maxTemp) {
    maxTemp = currentTemp;
  }

  // Hysterese: EIN bei Überschreiten tempOn, AUS bei Unterschreiten tempOff
  if (!fanState && currentTemp >= tempOn) {
    fanState = true;
    digitalWrite(FAN_PIN, HIGH);
    Serial.println("Lüfter EIN");
  } else if (fanState && currentTemp <= tempOff) {
    fanState = false;
    digitalWrite(FAN_PIN, LOW);
    Serial.println("Lüfter AUS");
  }
}

// ---------- HTTP: GET /status ----------
void handleStatus() {
  StaticJsonDocument<384> doc;
  if (isnan(currentTemp)) {
    doc["abluft_temp"] = nullptr;
  } else {
    doc["abluft_temp"] = (double)currentTemp;
  };
  if (isnan(minTemp)) {
    doc["abluft_temp_min"] = nullptr;
  } else {
    doc["abluft_temp_min"] = (double)minTemp;
  };
  if (isnan(maxTemp)) {
    doc["abluft_temp_max"] = nullptr;
  } else {
    doc["abluft_temp_max"] = (double)maxTemp;
  };
  if (isnan(currentHumidity)) {
    doc["abluft_humidity"] = nullptr;
  } else {
    doc["abluft_humidity"] = (double)currentHumidity;
  };
  doc["fan_state"] = fanState;
  doc["temp_on"] = tempOn;
  doc["temp_off"] = tempOff;

  String response;
  serializeJson(doc, response);
  server.send(200, "application/json", response);
}

// ---------- HTTP: GET/POST /config ----------
// Aufruf zum Ändern: /config?temp_on=45.0&temp_off=35.0
void handleConfig() {
  bool changed = false;
  float newTempOn = tempOn;
  float newTempOff = tempOff;

  if (server.hasArg("temp_on")) {
    newTempOn = server.arg("temp_on").toFloat();
    changed = true;
  }
  if (server.hasArg("temp_off")) {
    newTempOff = server.arg("temp_off").toFloat();
    changed = true;
  }

  if (changed) {
    if (newTempOff >= newTempOn) {
      server.send(400, "application/json",
        "{\"error\":\"temp_off muss kleiner als temp_on sein\"}");
      return;
    }
    tempOn = newTempOn;
    tempOff = newTempOff;
    saveThresholds(tempOn, tempOff);
  }

  StaticJsonDocument<128> doc;
  doc["temp_on"] = tempOn;
  doc["temp_off"] = tempOff;
  String response;
  serializeJson(doc, response);
  server.send(200, "application/json", response);
}

void setup() {
  Serial.begin(115200);
  delay(300);

  pinMode(FAN_PIN, OUTPUT);
  digitalWrite(FAN_PIN, LOW);

  loadThresholds();

  Wire.begin(I2C_SDA, I2C_SCL);
Serial.println("I2C scan:");
bool found = false;
for (uint8_t address = 1; address < 127; ++address) {
  Wire.beginTransmission(address);
  if (Wire.endTransmission() == 0) {
    Serial.printf("I2C-Geraet gefunden: 0x%02X\n", address);
    found = true;
  }
}
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

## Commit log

2026-09-19 STL-Dateien für den Gehäusedruck
    [ESP32-DisplayCase.stl, ESP32-DisplayCover.stl]
2026-09-20 Add ESP32 display cover 2 STL file
    [ESP32-DisplayCover-2.stl]
2026-09-27 Änderungen im Rahmen der Abluft Funktionalität
    [ESP32 Level Case and Lid.stl, LM2596 Case.stl]
2026-10-05 PipiTank Sensoren
2026-10-06 STL für Gehäuse hinzugefügt
    [PipiLevel Gehäuse-2.stl]
